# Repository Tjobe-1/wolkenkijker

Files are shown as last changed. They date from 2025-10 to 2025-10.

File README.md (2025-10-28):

# Wolkenkijker building instructions
Welcome to the Wolkenkijker instruction page! This repository contains all the files you need to build your own Wolkenkijker, or modify it to your liking. The instructions below assume you want to build a perfect copy. However, the Fusion360 file is included so you can customize the design.

**Wolkenkijker?** 

_Wolkenkijker captures the endless sky in a frame for your windowsill._\
Wolkenkijker (Cloud Viewer) frames what is always above us: the clouds. In an age where everything that deserves attention is given a frame, this object elevates the everyday into something worth exhibiting. The infinity of the sky is reduced to the intimacy of a picture frame – something small you can cherish and place on your windowsill. Inspired by Anish Kapoor’s Sky Mirror and the waist-level viewfinders of analog cameras, Wolkenkijker offers a second-degree way of observing: why do we insist on viewing everything through a frame, when sometimes we could simply look up? ([Tjeu'Studio](https://tjeu.studio/shop/wolkenkijker/))

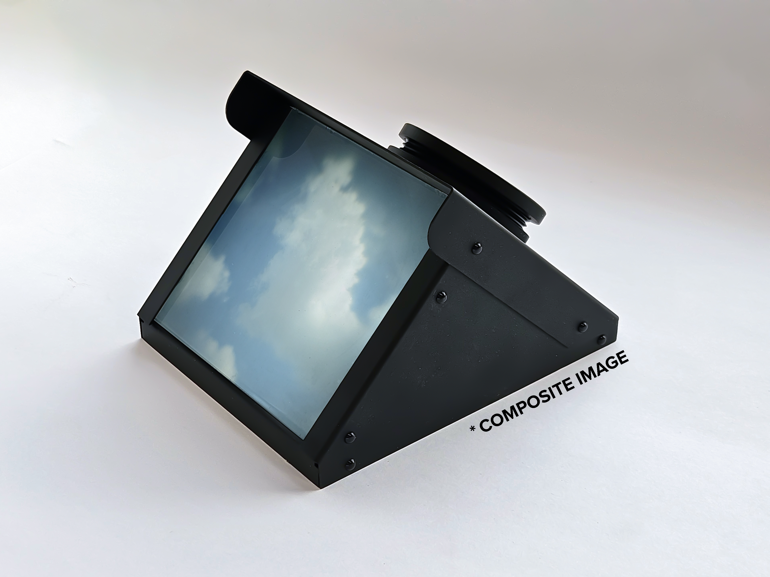
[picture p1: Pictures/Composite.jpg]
Image of a finished Wolkenkijker

_Note: this picture is of an earlier version. The version you will be making here has larger rivets, and one less rivet than pictured._

## Table of Contents
1. [Bill of Materials](#bill-of-materials)
2. [Manufacture the Aluminium Parts](#manufacture-the-aluminium-parts)
3. [Print the 3D Prints](#print-the-3d-prints)
4. [Grind the Ground Glass](#grind-the-ground-glass)
5. [Assemble Your Wolkenkijker](#assemble-your-wolkenkijker)
6. [Possible Alternative Materials](#possible-alternative-materials)
7. [Contribute](#contribute)

## Bill of materials
- Picture frame glass (min. 100 x 100 mm, thickness 1 mm)
- Silicon carbide grinding powder (400 and 600 grit)
- [Biconvex lens](https://nl.aliexpress.com/item/1005007494613338.html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) (D 50 F 95.5 mm)
- [Fresnel lens](https://nl.aliexpress.com/item/1005008116547795.html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) (focal length 120 mm, dimensions 100 x 100 mm)
- [Front surface mirror](https://nl.aliexpress.com/item/1005004853298387.html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) 123 x 100 mm, thickness 1.1 mm. [This supplier](https://www.aliexpress.com/store/1100386575?spm=a2g0o.detail.0.0.79d4c7iEc7iE3z) makes custom sized mirrors.
- [Push rivets](https://nl.aliexpress.com/item/1005008732939550.html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) (get the [R3535 in black](Manufacturing/Push%20rivet%20specs.jpeg), picture linked for specifications)
- Glass cutter

## Manufacture the aluminium parts
[STEP file for the 1mm aluminium parts](Manufacturing/Sheet%20metal%201mm.step) 

I had the aluminium parts produced by a manufacturer who laser cut, bent, and anodized them. [JLCCNC](https://jlccnc.com/sheet-metal-quote) is fast and affordable. Use 1 mm thick 5052 aluminum, anodized black.

## Print the 3D prints
Download the [3D print files](Manufacturing/3D%20Print/).

The lens assembly looks best printed in resin. I used [JLC3DP](https://jlc3dp.com/) for printing.

## Grind the ground glass and cut fresnel lens
1. Cut the glass to size (100 x 90 mm)
2. Sand down the sharp edges of the glass
3. Grind the glass following [this video tutorial](https://www.youtube.com/watch?v=RVCxuESAiCw).
4. Cut the fresnel lens to the same size as the glass

⚠️ **Safety Tip**: Wear gloves and eye protection when cutting or grinding glass. 

## Assemble your Wolkenkijker
1. Adhere the mirror to the bottom aluminium plate using your preferred adhesive.
2. Sanwich the glass and fresnel lens together, and use the glass connector pieces to keep them stuck together. The smooth side of the fresnel lens and the ground side of the glass should be paired up. 
3. Follow the [assembly instructions PDF](Assembly%20manual/Wolkenkijker%20assembly%20instruction.pdf).

## Possible Alternative Materials
- Aluminium parts can be replaced by other sheet materials. The files are based on 1 mm thickness. Cardboard prototypes worked well.
- Ground glass can be substituted with pre-ground glass. Baking sheets were used as placeholders during prototyping.

## Contribute
- **Want to contribute?** Fork the repo, submit pull requests, or share your build photos!
- **Credit & Remixing:** If you build a Wolkenkijker, I’d love to hear about it! Please credit this project, and consider linking back here if you remix or share your own version.

---
**Version**: 1.0  
**Last updated**: October 2025

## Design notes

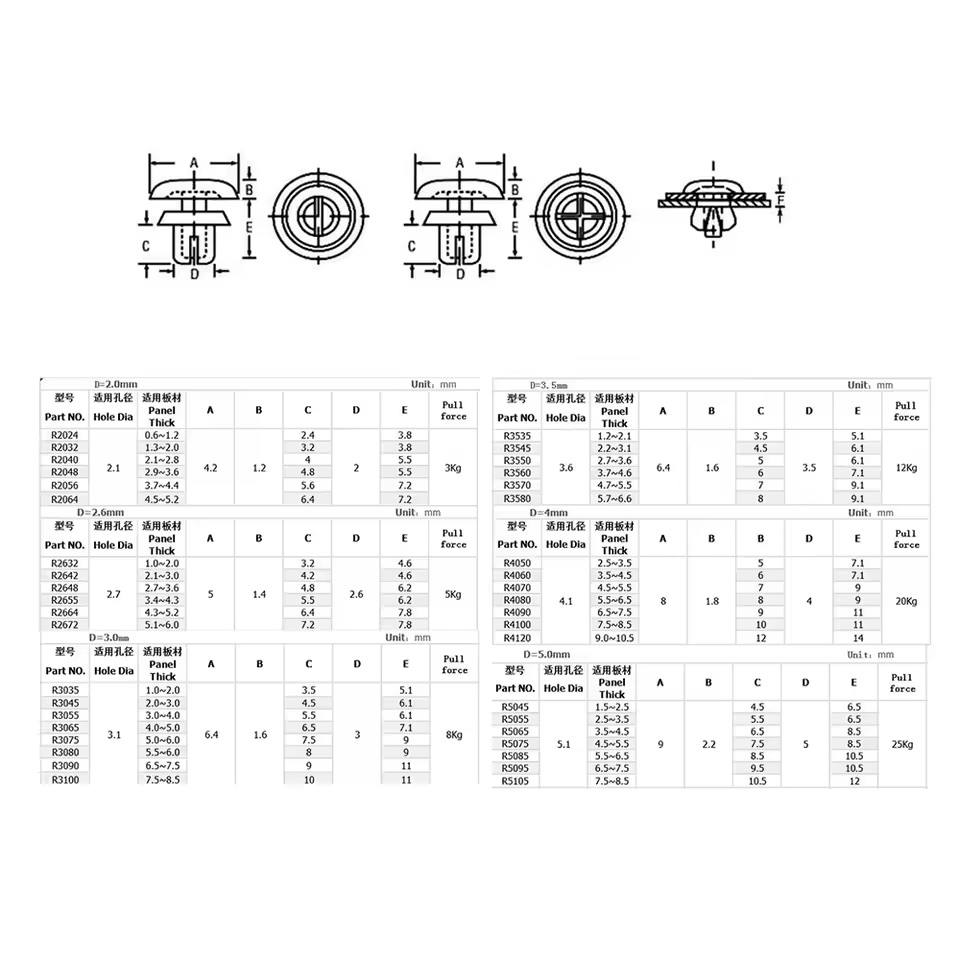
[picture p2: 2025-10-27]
Manufacturing/Push rivet specs.jpeg

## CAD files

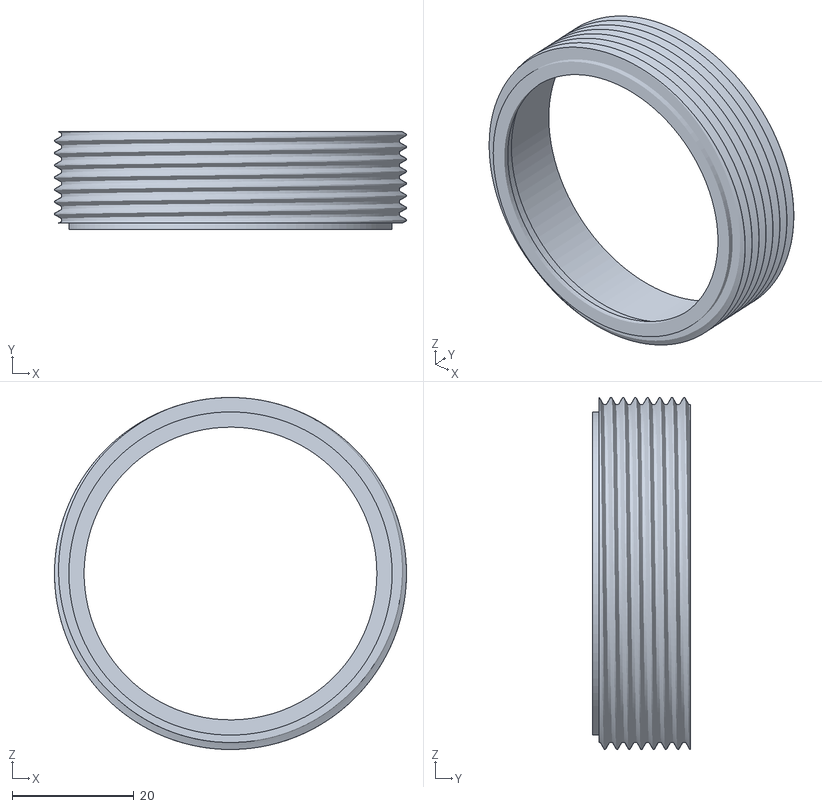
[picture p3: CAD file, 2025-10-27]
Manufacturing/3D Print/Lens thread.stl
57.7 x 16.0 x 57.7

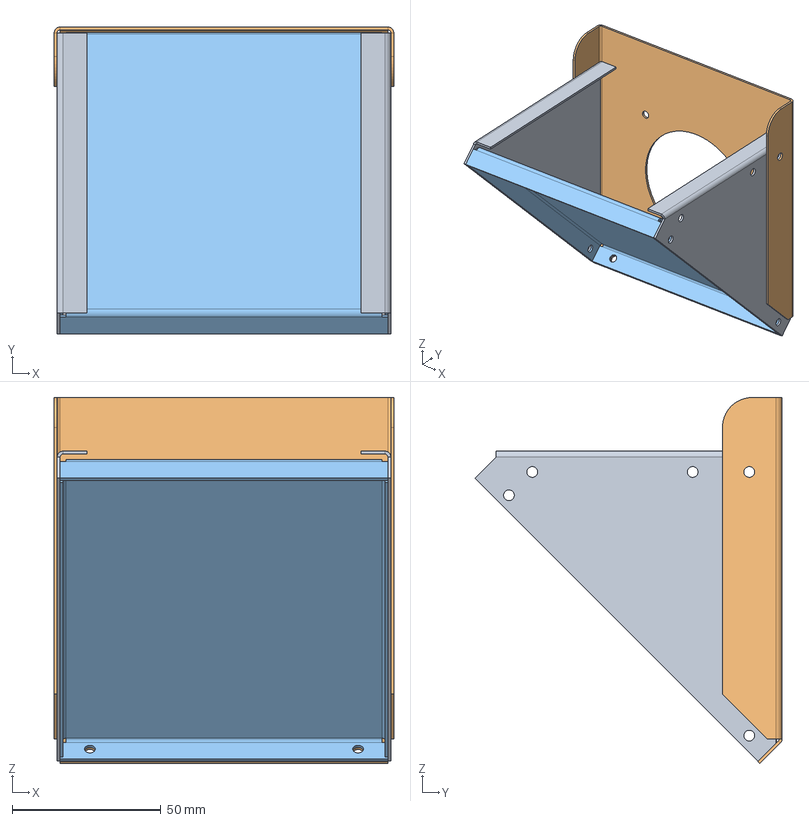
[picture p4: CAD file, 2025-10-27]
Manufacturing/Sheet metal 1mm.step
114.0 x 103.1 x 122.8 mm
left
top
right
mirror

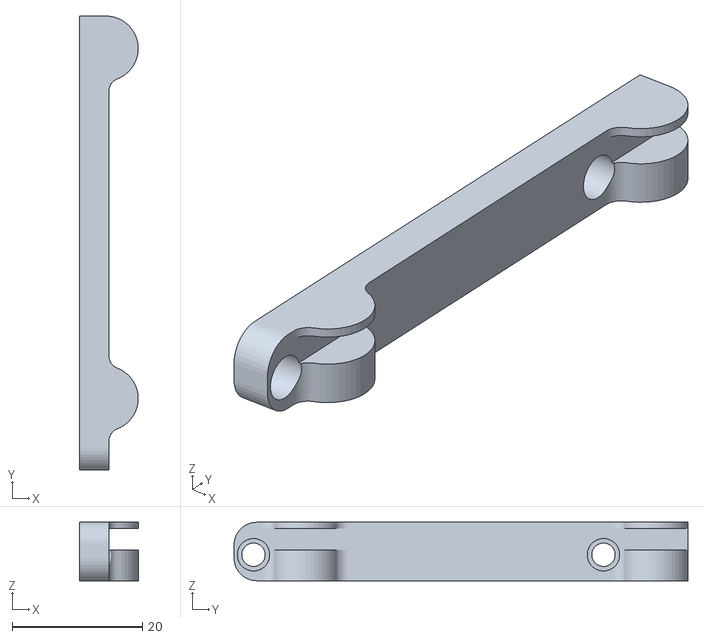
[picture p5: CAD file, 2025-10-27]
Manufacturing/3D Print/Glass holder left.stl
9.00 x 69.8 x 9.00

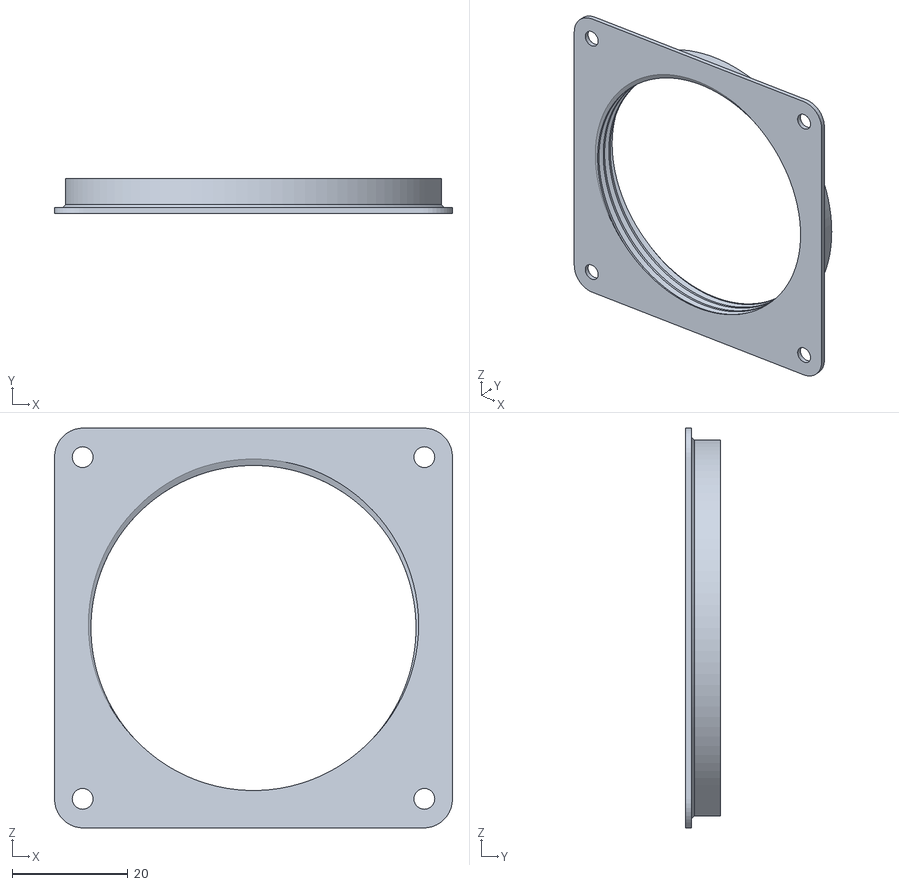
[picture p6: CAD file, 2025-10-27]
Manufacturing/3D Print/Lens mount.stl
68.7 x 6.01 x 69.1

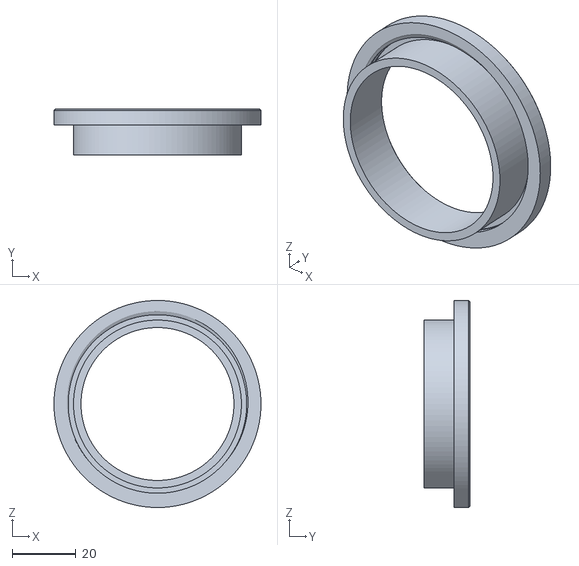
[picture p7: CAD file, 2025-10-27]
Manufacturing/3D Print/Lens holder.stl
65.0 x 14.5 x 65.0

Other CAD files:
Manufacturing/3D Print/Glass holder right.stl
Manufacturing/Wolkenkijker.f3d

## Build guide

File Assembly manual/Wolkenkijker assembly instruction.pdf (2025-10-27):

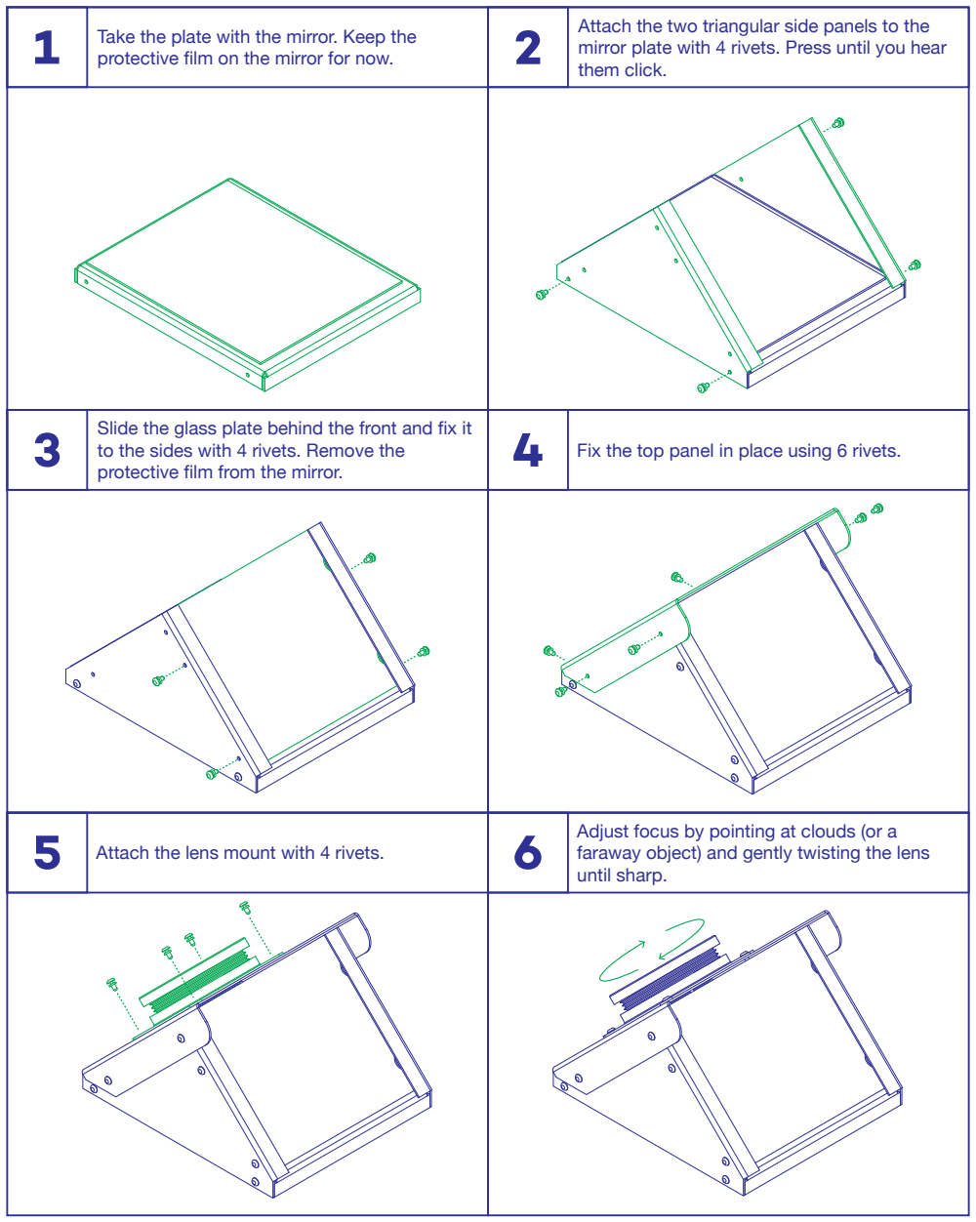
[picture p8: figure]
protective film on the mirror for now.; them click.; to the sides with 4 rivets. Remove the protective film from the mirror.; Attach the lens mount with 4 rivets.; until sharp.

Take the plate with the mirror. Keep the

Attach the two triangular side panels to the mirror plate with 4 rivets. Press until you hear

Slide the glass plate behind the front and fix it Fix the top panel in place using 6 rivets.

Adjust focus by pointing at clouds (or a faraway object) and gently twisting the lens

Wolkenkijker - assembly instruction
Assemble your Wolkenkijker by attaching each new part with the supplied push rivets.
In each step, the new parts to attach are shown in green.
- To use a rivet: align the holes, insert the narrow end, and press the round head until it clicks.
- To disassemble, slide a thin tool (like a knife) under the rivet head and pull it out.

https://tjeu.studio
